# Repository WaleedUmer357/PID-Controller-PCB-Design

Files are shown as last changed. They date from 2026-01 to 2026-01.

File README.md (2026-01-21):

<h3>🔌 PCB Design Project</h3>

- <b><a href="https://github.com/WaleedUmer357/PID-Controller-">PID Controller</a></b>
  - Professional analog PID controller with TL072P operational amplifiers
  - <a href="5336317_Waleed_UMER_PID_Controller.pdf">Documentation</a> | <a href="Images/PCB_schematic.pdf">Schematic</a> | <a href="PCB.png">PCB Layout</a>

  <details>
  <summary>🎨 Click to view Project Details</summary>
  <br>
  
  <h4>🚀 Project Overview</h4>
  <p>This project showcases a professional analog PID (Proportional-Integral-Derivative) controller circuit designed and implemented using TL072P operational amplifiers. The controller was developed as part of Practical Electronics coursework at Griffith University, featuring comprehensive design, simulation, breadboard prototyping, and final PCB implementation. The system demonstrates precise control system principles with detailed analysis of P, PI, PD, and PID behaviors under various signal conditions.</p>
  
  <h4>✨ Key Features</h4>
  <ul>
    <li><b>Controller Type:</b> Analog PID Controller with adjustable parameters</li>
    <li><b>Operational Amplifiers:</b> TL072P Low-Noise JFET Op-Amps for high precision</li>
    <li><b>Frequency Range:</b> 5Hz to 20kHz operational range</li>
    <li><b>Control Stages:</b> Independent Proportional, Integral, and Derivative circuits</li>
    <li><b>Adjustability:</b> Trimpot potentiometers for real-time tuning</li>
    <li><b>Test Points:</b> Multiple test points for signal monitoring and analysis</li>
  </ul>
  
  <h4>🎯 Design Implementation</h4>
  
  <p><b>🔧 Circuit Stages Design</b></p>
  <ul>
    <li><b>Proportional Stage:</b> Gain Kp = 10 with trimpot adjustment capability</li>
    <li><b>Integral Stage:</b> Low-pass filter with cutoff frequency = 800Hz, Ki = 1</li>
    <li><b>Derivative Stage:</b> High-pass filter with Kd = 1 for rate-of-change response</li>
    <li><b>Summation Stage:</b> Standardized 1KΩ resistors with overall gain of 10</li>
    <li><b>Difference Amplifier:</b> Unit gain stage for error signal processing</li>
  </ul>
  
  <p><b>⚡ Power Requirements</b></p>
  <ul>
    <li>Dual power supply: ±12V to ±15V operation</li>
    <li>Low power consumption JFET input op-amps</li>
    <li>Stable operation across temperature variations</li>
  </ul>
  
  <p><b>📊 Signal Processing Capabilities</b></p>
  <ul>
    <li>Handles square, triangular, and sinusoidal waveforms</li>
    <li>Real-time error correction with minimal phase shift</li>
    <li>Overshoot and undershoot control through tuning</li>
    <li>Steady-state error elimination via integral action</li>
  </ul>
  
  <h4>🔬 Testing & Performance Analysis</h4>
  
  <p><b>📈 Controller Behaviors Demonstrated</b></p>
  
  <table>
    <tr>
      <td><b>Controller Type</b></td>
      <td><b>Performance Characteristics</b></td>
      <td><b>Applications</b></td>
    </tr>
    <tr>
      <td>Proportional (P)</td>
      <td>Fast response, steady-state error, oscillations</td>
      <td>Simple systems, coarse control</td>
    </tr>
    <tr>
      <td>Proportional-Integral (PI)</td>
      <td>Eliminates steady-state error, overshoot issues</td>
      <td>Temperature control, level control</td>
    </tr>
    <tr>
      <td>Proportional-Derivative (PD)</td>
      <td>Reduces overshoot, system damping, undershoot</td>
      <td>Motor control, positioning systems</td>
    </tr>
    <tr>
      <td>Full PID</td>
      <td>Optimal response, minimal error, stability</td>
      <td>Precision control systems</td>
    </tr>
  </table>
  
  <p><b>🎛️ Tuning Methodology</b></p>
  <ul>
    <li>Manual tuning via potentiometers for each stage</li>
    <li>Oscilloscope monitoring of reference vs. output signals</li>
    <li>Iterative adjustment for optimal response</li>
    <li>Frequency response analysis from 5Hz to 20kHz</li>
  </ul>
  
  <h4>🖼️ Design Gallery</h4>
  
  <p><b>📋 Complete Schematic Design</b></p>
  <p>Professional schematic showing all PID stages with component values and signal flow. Designed in Altium Designer with clear functional blocks.</p>
  PID Controller Schematic
  
  <p><b>🔌 PCB Layout - Top View</b></p>
  <p>Clean, professional PCB layout with optimized component placement. Single-sided design for easy manufacturing and assembly.</p>
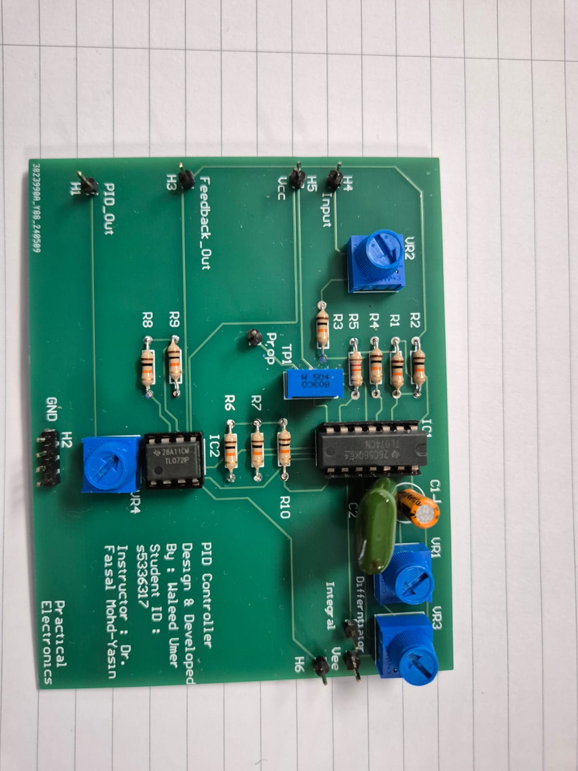
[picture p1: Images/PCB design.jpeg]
PCB Layout
  
  
  <p><b>⚡ Circuit Implementation</b></p>
  <p>Detailed view of the analog PID circuit implementation with operational amplifiers, resistors, capacitors, and tuning potentiometers.</p>
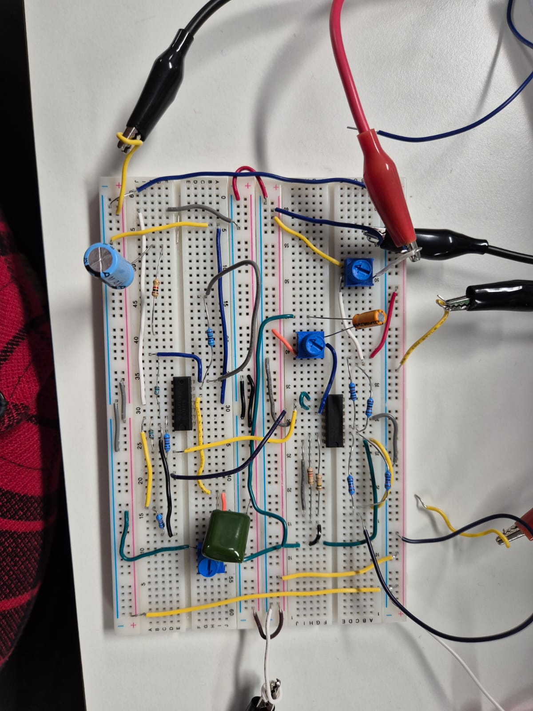
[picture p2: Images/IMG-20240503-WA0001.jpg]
Circuit Implementation
  
  
  <p><b>🧪 Breadboard Prototype</b></p>
  <p>Initial breadboard implementation used for circuit validation and parameter tuning before PCB fabrication.</p>
  <p><i>Refer to Figure 3.3 in documentation</i></p>
  
  <h4>📐 Technical Specifications</h4>
  <table>
    <tr>
      <td><b>Operational Amplifiers</b></td>
      <td>TL072P (x2), TL074 (x1)</td>
    </tr>
    <tr>
      <td><b>Power Supply</b></td>
      <td>±12V to ±15V DC</td>
    </tr>
    <tr>
      <td><b>Frequency Range</b></td>
      <td>5Hz - 20kHz</td>
    </tr>
    <tr>
      <td><b>Proportional Gain</b></td>
      <td>Kp = 10 (adjustable)</td>
    </tr>
    <tr>
      <td><b>Integral Time</b></td>
      <td>Ti = 1/(2π×800) seconds</td>
    </tr>
    <tr>
      <td><b>Derivative Time</b></td>
      <td>Td = 1/(2π×cutoff) seconds</td>
    </tr>
    <tr>
      <td><b>PCB Dimensions</b></td>
      <td>Approx. 80mm x 60mm</td>
    </tr>
    <tr>
      <td><b>PCB Layers</b></td>
      <td>Single-sided with ground plane</td>
    </tr>
    <tr>
      <td><b>Connectors</b></td>
      <td>4-pin headers for I/O and power</td>
    </tr>
  </table>
  
  <h4>📊 Performance Results</h4>
  
  <p><b>✅ Successful Outcomes</b></p>
  <ul>
    <li>Full PID functionality achieved with all control modes</li>
    <li>Effective error correction for various input waveforms</li>
    <li>Stable operation across specified frequency range</li>
    <li>Minimal overshoot with proper tuning (＜10%)</li>
    <li>Steady-state error elimination via integral action</li>
  </ul>
  
  <p><b>⚠️ Identified Limitations</b></p>
  <ul>
    <li>Frequency response limited to 20kHz maximum</li>
    <li>Low-frequency behavior resembles P-only controller below 5Hz</li>
    <li>Triangular/sinusoidal signals limited to 300Hz for full PID action</li>
    <li>Requires external load for practical applications</li>
  </ul>
  
  <h4>🔮 Applications</h4>
  <ul>
    <li><b>Temperature Control Systems:</b> HVAC, industrial process control</li>
    <li><b>Motor Speed Control:</b> DC motor speed regulation, conveyor systems</li>
    <li><b>Process Control:</b> Chemical reactors, distillation columns</li>
    <li><b>Educational Tool:</b> Control systems laboratory experiments</li>
    <li><b>Prototyping Platform:</b> PID algorithm testing and validation</li>
  </ul>
  
  <h4>📈 Comparative Analysis</h4>
  
  <p><b>PID vs. Other Controllers</b></p>
  <ul>
    <li><b>vs. P-only:</b> PID eliminates steady-state error and reduces oscillations</li>
    <li><b>vs. PI:</b> PID adds derivative action to reduce overshoot and improve stability</li>
    <li><b>vs. PD:</b> PID includes integral action to eliminate steady-state error</li>
    <li><b>Overall:</b> PID provides balanced response with fastest settling time</li>
  </ul>
  
  <h4>🔧 Design Tools & Methodology</h4>
  <ul>
    <li><b>Simulation:</b> Proteus for initial circuit validation</li>
    <li><b>Schematic Capture:</b> Altium Designer for professional schematic design</li>
    <li><b>PCB Layout:</b> Altium Designer with design rule checking</li>
    <li><b>Prototyping:</b> Breadboard for initial testing and parameter tuning</li>
    <li><b>Testing:</b> Oscilloscope for waveform analysis and performance validation</li>
  </ul>
  
  <h4>📦 Project Files</h4>
  <ul>
    <li><b>Complete Documentation:</b> <a href="5336317_Waleed_UMER_PID_Controller.pdf">PID Controller Report (PDF)</a></li>
    <li><b>Schematic:</b> <a href="PCB_schematic.pdf">Altium Schematic</a></li>
    <li><b>PCB Layout:</b> <a href="PCB.png">Manufacturing-ready Layout</a></li>
    <li><b>Circuit Diagram:</b> <a href="PCB design.jpeg">Detailed Circuit Implementation</a></li>
    <li><b>Bill of Materials:</b> Included in documentation (page 4)</li>
  </ul>
  
  <h4>💡 Future Improvements</h4>
  <ul>
    <li>Implement digital PID control using microcontroller</li>
    <li>Add auto-tuning capability for different loads</li>
    <li>Extend frequency range with higher-order filters</li>
    <li>Include load driver stage for motor/actuator control</li>
    <li>Develop graphical user interface for parameter adjustment</li>
    <li>Implement adaptive PID for varying system dynamics</li>
  </ul>
  
  <h4>📚 References</h4>
  <ol>
    <li>Åström, K. J., & Murray, R. M. (2008). Feedback Systems: An Introduction for Scientists and Engineers. Princeton University Press.</li>
    <li>Åström, K. J., & Hägglund, T. (1995). PID Controllers: Theory, Design, and Tuning. Instrument Society of America.</li>
    <li>Texas Instruments. (2020). TL07xx Low-Noise FET-Input Operational Amplifiers Datasheet.</li>
    <li>Hägglund, T., & Åström, K. J. (2004). Revisiting the Ziegler-Nichols step response method for PID control. Journal of Process Control.</li>
    <li>Ogata, K. (2010). Modern Control Engineering (5th ed.). Prentice Hall.</li>
  </ol>
  
  <p><b>Designer:</b> Waleed Umer (S5336317) | Griffith University</p>
  <p><b>Course:</b> Practical Electronics | Instructor: Dr. Faisal Mohd-Yasin</p>
  <p><b>Project Date:</b> 2024</p>
  <p><b>Tools Used:</b> Altium Designer, Proteus, Oscilloscope, Breadboard</p>
  
  </details>

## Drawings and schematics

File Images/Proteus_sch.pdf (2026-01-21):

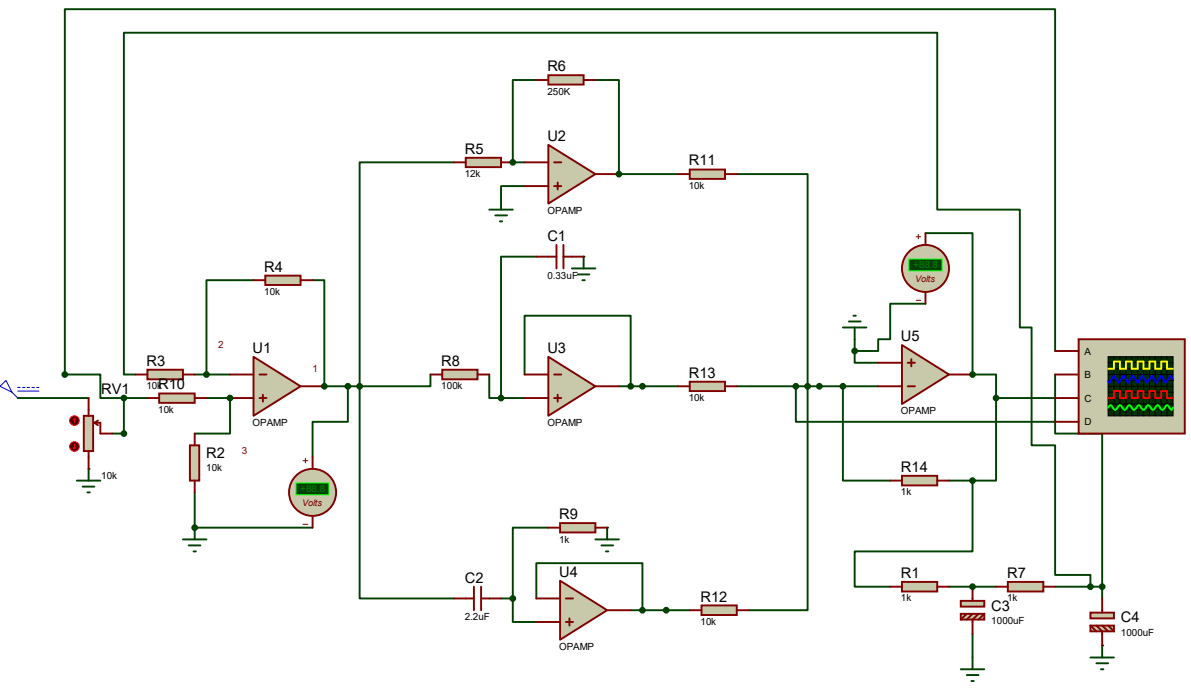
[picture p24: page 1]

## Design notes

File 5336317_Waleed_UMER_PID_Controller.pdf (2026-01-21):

PID Controller | June 6, 2024

# PID CONTROLLER

## Waleed Umer – S5336317

## PRACTICAL ELECTRONICS

### Instructor : Dr. Faisal Mohd-Yasin

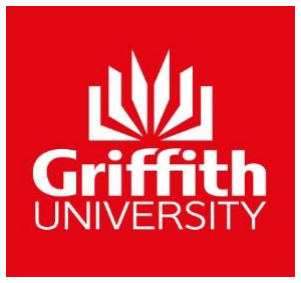
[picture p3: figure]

## CONTENTS

## 1.0 - INTRODUCTION

OBJECTIVES AND OUTCOMES

The main objective of the project is to apply the knowledge acquired in practical electronics to

the design and implementation of a PID controller. It also aims to explore and develop every

step required to build an electronic prototype. The expected results of the project will provide

a comprehensive understanding of electronic components (operational amplifiers, resistors,

capacitors, sensors, etc.) and their configurations in real-world applications.

On the topic of PID controllers, the project is detailed in its explanation. Although it does not

present any real-world applications, it explains the different modes of operation of the PID

controller—P, PI, PD, and PID—when the setpoint command is a sinusoidal, impulse,

triangular, or square wave signal.

Each mode has its advantages and disadvantages which are discussed, as are the frequencies

where these limitations exist. This analysis provides the unique advantages and disadvantages

of each mode and provides a comprehensive view of how each mode performs under different

conditions.

## 2.0 - APPLICATION

The PID controller, as we have seen, can be a useful part of the controllers we use in practical

control systems. This section will highlight three significant applications of PID controllers in

the real world:

1. Temperature control : We mentioned earlier that keeping the temperature in our houses

regulated is an essential aspect of heating, ventilation, and air-conditioning (HVAC) systems.

Not surprisingly, PID control is also commonly used in industrial applications where we need

to keep the temperature of something that can change quickly. For example, one could for

controlling the temperature in a furnace. This would be where the temperature of a furnace

must remain at a precise temperature to achieve consistent results, even with fluctuations or

disturbance in the system [4].

2. Speed control: Being able to accurately and precisely control the speed of a motor is

another application of PID control. For example, with a car engine, you want a certain amount

of gas to go in your engine to achieve a desired speed. Through PID control, one can regulate

the flow of gas into the engine to achieve a certain, desired speed. This is seen in the

automation of a conveyor belt system where you want to move a give a belt a certain speed

from the motor [5].

3. Process control: This last example can be applied in a situation where you have a chemical

process you want to control. This could be a chemical reactor where you are trying to produce

a specific amount of product Y from reactants X1 and X2. This system will run optimally with

the right amount of reactants being pumped in. A PID controller will adjust the flow rates to

make sure we have the right pressure and composition to help the distillation column run

efficiently, ensuring the results are consistent[6].

MARKET ANALYSIS

Without undergoing extensive practical tests with a load such as a DC motor, the product has

no potential commercial value for application. Nonetheless, it can be used in a range of signal

control applications within a specified range.

The below are the costs for individual components using the circuit; the minimum quantity of

PCBs that can be ordered to manufacture is five per quantity and the costs for PCB production

is $18, and the delivery charge is an additional $5.

COST OF THE PROJECT
LIST OF PARTS¹
Comment | Description | Quantity | Total Cost AUD
CAPACITOR POL | Polarized Cap | 1 | $1.92
TL074 | TL074/LF347 Quad Low Noise JFET Op-
| Amp Linear [3] | 1 | $1.58
Header 4 | Header, 4-Pin | 4 | $1.10
TL072 | TL072 Bi Low Noise JFET Op-
| Amp Linear | 1 | $1.66
RESISTOR | 1/4 W Res | 11 | $7.52
Potentiometer | Breadboard Compatible | 4 | $7.00
Manufacturing &
Delivery | Printed Circuit Board | | 18+5$

TOTAL COST OF
MATERIALS | $43.78

LABOR COST
ACTIVITY | HOURS | COST PER HOUR | TOTAL COST
Altium design | 4 | $25 | $100
Circuit wiring and testing | 12 | $25 | $300
Soldering process | 2 | $20 | $40
TOTAL COST OF LABOR | | | $440

TOTAL COST OF THE PROJECT
Developing, testing, and producing the prototype not only involves high initial costs, but also involves

relatively simple parts and functions. Our cost estimate for the materials, including PCB manufacturing

and shipping, is approximately $44 based on current online prices. For mass production, parts would be

sourced at wholesale prices significantly decreasing the costs. Our production quality and cost-

effectiveness could be enhanced by streamlining the soldering process. Overall, the total cost to develop

and produce the prototype is approximately $440.

## 3.0 -INITIAL DESIGN

BASIC THEORY

A Proportional-Integral-Derivative (PID) controller is an indispensable instrument in control

systems engineering and is ubiquitous in modern industry. It’s a system that keeps a process

within a given setpoint by minimising the error between the process variable and the setpoint.

One computes the controller output from three parts: the first one (P) relies on the current error,

a second one (I) accumulates errors over time, and a third (D) anticipates future errors by

considering the rate of change of error. Hence, the combined effect makes the system behave in

such a way that it truly knows how to deliver desired adequate tuning for precise and stable

control of a large class of dynamic systems[1],[2].

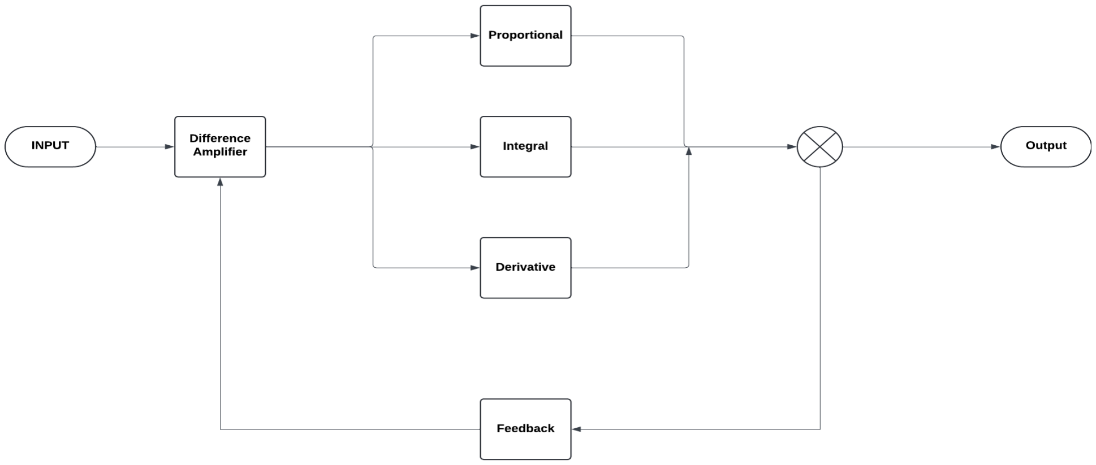
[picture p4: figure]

Figure 3.01 Basic PID Diagram

ELEMENTS OF A PID

PROPORTIONAL STAGE
Proportional is the part of a PID Controller that puts a gain on the error signal. It dictates how

much of a gain this Controller will see from the error to the setpoint. The goal is to dictate

the gain of the system, and the percent of not only the Controller but also on the overall

system. So the proportional gain (Kc) will define in turn how much but also very quickly this

system will react to this error signal. If we take a proportional gain that is very high, we can

see a very quick reaction and this system can start to ‘oscillate’.

INTEGRAL STAGE
A PID controller, on the other hand, incorporates a short-term memory that increases the

responsiveness by accumulating past errors. This accumulated value is used to change the

setpoint of the controlled output in order to bring the process variable more quickly to its

desired value. The gain of this component is determined by the chosen ratio between the

feedback capacitor and the resistor, ensuring errors of long duration will be eliminated,

eventually.

DERIVATIVE STAGE
The differentiator part of a PID controller quantifies the error’s time rate of change,

contributing a negative value to the controlled output as the growth rate of the error increases.

It reduces overshoot by slowing down system response at approach to set-point by process variable, thus, ideally preventing any overshooting. When there are big deviations in the

system, derivative component performs a significant task to ensure that it runs smoothly. It

also minimizes oscillations and helps settle down the system along with an integral portion.

ANALOGUE CIRCUITS OF PID:
The PID controller design process consisted of different stages.

Initially, the analogue circuits belonging to the proportional, integral, derivative, summation

and subtractor stages were defined. The topology used in each stage are shown below:

1. Proportional circuit:

Gain = Kp=10

We chose a moderate gain for the proportional stage to ensure that the PID output approaches

the reference value quickly, meeting our requirement for systems with moderate to high

frequencies. This not only shortens the response time but also makes it easier to observe the

PID signal intercepting the system signal, especially during demonstrations with an

oscilloscope. Initially, we set this gain, but later, we can fine-tune it to the desired value using

a Trimpot (potentiometer) simply by adjusting its knob.

2. Integral circuit:

voltage gain=Ki=1

CutOff Frequency =800Hz

To maintain circuit simplicity, the gain value of the integral stage was set to 1, and a low-pass

integral filter output was buffered with a gain of 1, deviating from the conventional integral

circuit. This adjustment streamlined circuit analysis. To offset the lack of gain in the integral,

gain was introduced to the summing stage of the PID circuit. This modification ensures proper

functionality and simplifies the overall circuit design.

3. Differentiation circuit:

Derivative gain = Kd = 1

To maintain circuit simplicity, similar to integral stage, the gain value of the derivative stage

was set to 1, and a low-pass differential filter output was buffered with a gain of 1, deviating

from the conventional differential circuit. This adjustment streamlined circuit analysis. To offset

the lack of gain in the differential stage, gain was introduced to the summing stage of the PID

circuit. This modification ensures proper functionality and simplifies the overall circuit design.

4. Summation circuit:

To simplify the design process, all resistors were standardized to the same value (1 KΩ).

Since we set gain of the integral and differential stage of the circuit , a gain of 10 is introduced

at the summation stage . This approach maintains signal integrity and facilitates

straightforward analysis and adjustment of the circuit.

5. Difference Amplifier circuit:

Similarly to the summation stage, unit gains are established for the difference amplification

stage initially to maintain the system's performance unaffected. This approach ensures

stability and consistency in the system's operation, minimizing any potential impact on its

overall performance.

ASSEMBLED PID CONTROLLER CIRCUIT:

Employing the Proteus circuit design software , entire PID controller was modelled and an

approximate response of the system was obtained. In the following image you can see the

integration of all the circuits mentioned in the previous section.

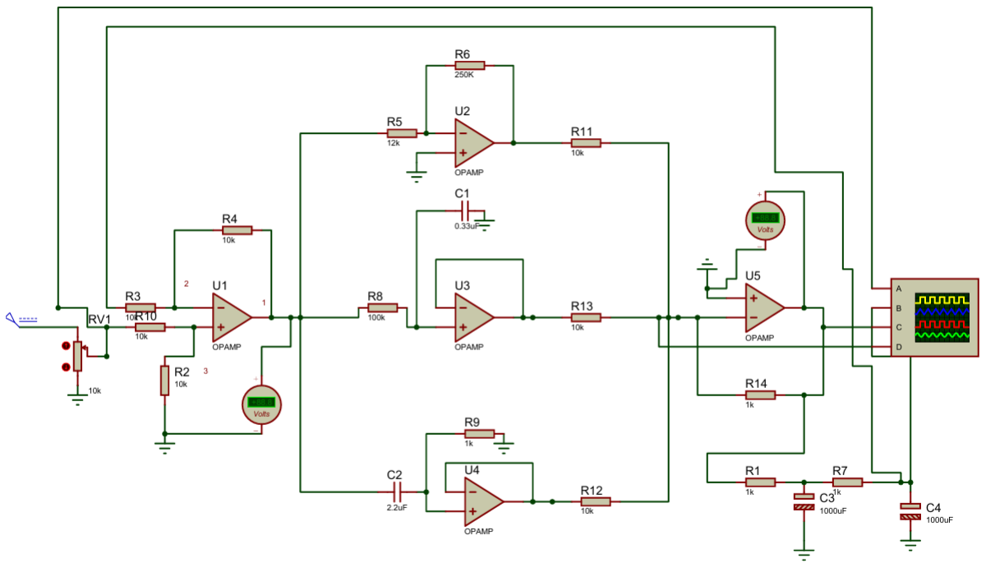
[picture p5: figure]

Figure 3.02 Proteus Implementation of PID

In this Figure 3.2 . A simulated circuit of PID controller shown on proteus

BREADBOARD CIRCUIT RESULT

The simulated system was transferred to real circuits and elements on a breadboard. The result

of this implementation is shown below Figure 3.3.

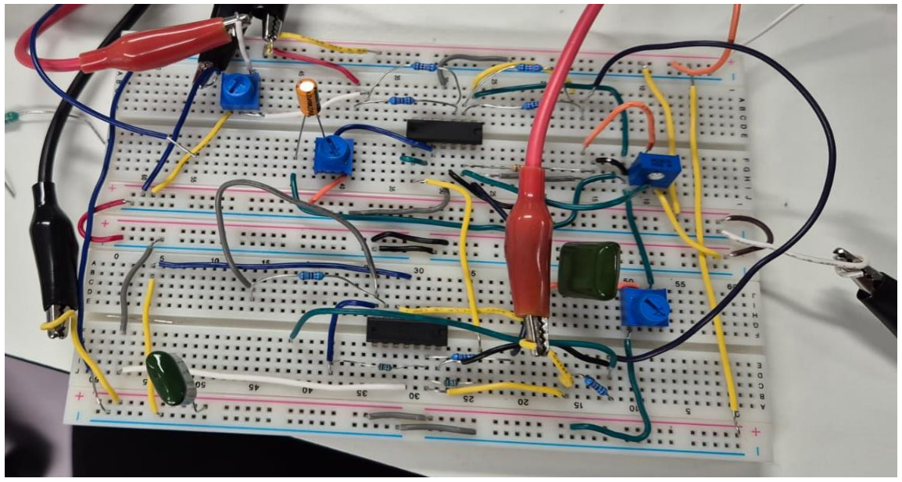
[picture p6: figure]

Figure 3.3 Breadboard Implementation of PID

This circuit played a crucial role in conducting a wide range of tests, allowing for modifications

to resistors, capacitors, op-amps, and transistors. Through these tests, we were able to define

the response characteristics of the desired PID system, subsequently obtaining the values of

fixed resistors and capacitors. These values were then applied practically on the PCB,

facilitating an efficient and effective implementation process.

ALTIUM PCB AND SCHEMATIC DESIGN

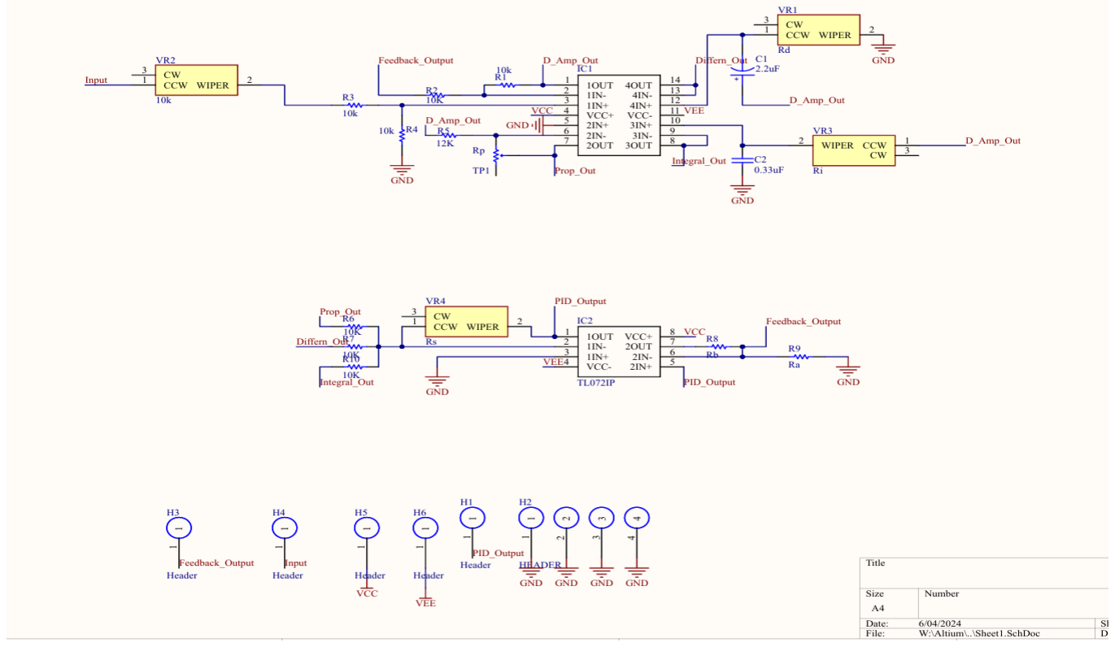
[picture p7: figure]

Figure 03.4 PCB Schematic of PID

We started our circuit design journey in Proteus, which made simulating and tweaking

component values a breeze. After settling on the initial design, we shifted gears to Altium, where

countless hours were spent refining and discussing component choices and how they fit into

our circuit.

Once we were happy with the design, we dove into PCB layout, going through three iterations

before we had a final version ready for manufacturing. We relied heavily on the component

libraries provided by the lab attendant in Altium.

We made sure to keep things simple by sticking to single-sided PCB tracks,

making manual soldering a lot easier and reducing the risk of damaging anything.

### Plus, we included a ground plane on the bottom side of the board for added

stability. Figure 3.5 shows manufacturing script of PCB design

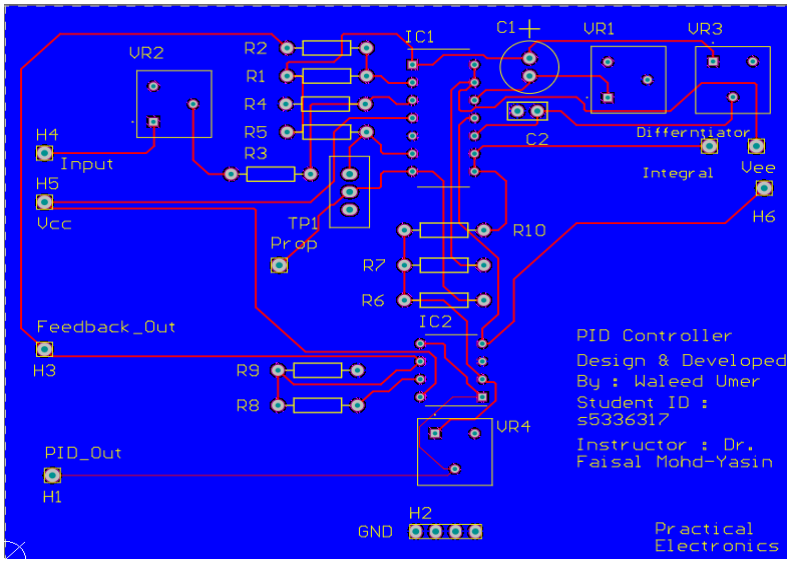
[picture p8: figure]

Figure 3.5 PCB Manufacturing Script of PID

## 4.0 – System Design Characteristics & Analysis

The system design underwent thorough testing and analysis on both breadboard and PCB

platforms, yielding valuable insights. An additional Proportional stage was introduced in the

PCB circuit as a modification. The results of various controller circuit behaviours were

categorized and explained, highlighting the benefits and drawbacks of each approach.

Throughout the analysis, it became evident that while alternative circuits showed promise in

certain scenarios, they were not preferred over a full PID controller. The drawbacks of these

circuits, such as limited control accuracy or instability, were identified and solutions were

proposed. These findings underscored the importance of a comprehensive PID controller design

for optimal performance and versatility in various control applications.

Breadboard Results
The response of this circuit measured by the oscilloscope is shown below (Figure 4.2). The

reference signal (yellow) and the PID signal (green) at different gain values for Kp , Ki and

Kd. The figure below is taken from the pre-liminary design powerpoint where I explained the

behaviour of the circuit.

Key Takeaways from Breadboard Demonstration:

- The left PID output demonstrates high stability, achieved by suppressing steady-state error

and overshoot through circuit tuning with the potentiometer.

- Conversely, the right output exhibits overshoot, indicating a need for tuning the integral value

to optimize performance.

- -The middle circuit, however, shows balanced gain values, as evidenced by the absence of

significant overshoot, or undershoot. This indicates that it effectively incorporates the

functionalities of all PID elements.

- As demonstrated in the lab, without fine-tuning the circuit for a given signal, the output can

become distorted.

- A square wave signal was chosen for demonstration due to its abrupt changes, offering a clear

illustration of the circuit's response. The same cannot be said for sinusoidal and triangular

signals, which do not provide as distinct a demonstration of the circuit's behaviour.

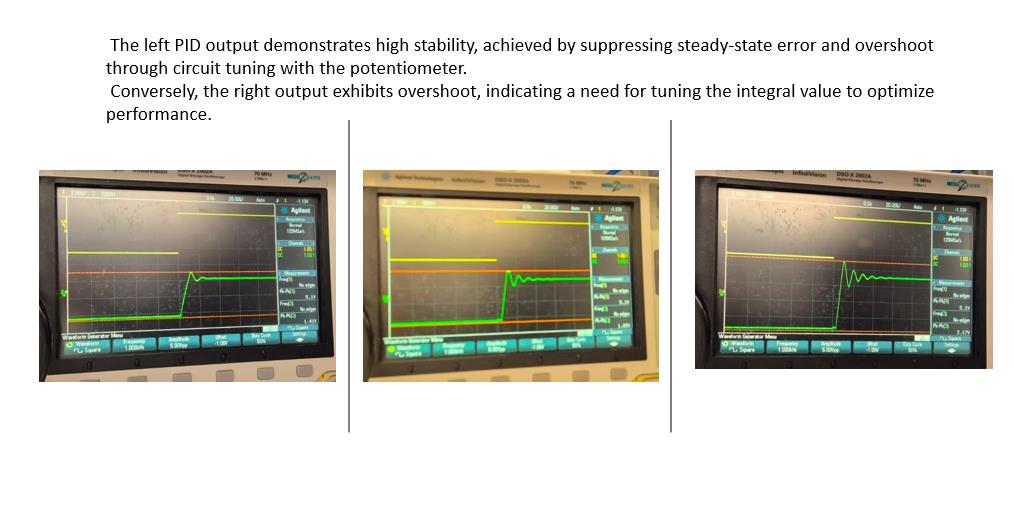
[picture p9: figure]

Figure 4.1 Breadboard results at different Tuning Values (Kp,Ki & Kd)

PRINTED CIRCUIT BOARD:

The final product is visually represented in the images below. The PCB appears clean and

compact, presenting a professional appearance. Most connections are tidy and precise,

contributing to the overall neatness of the assembly. Moreover, the PID controller operates as

anticipated, demonstrating its functionality and reliability.

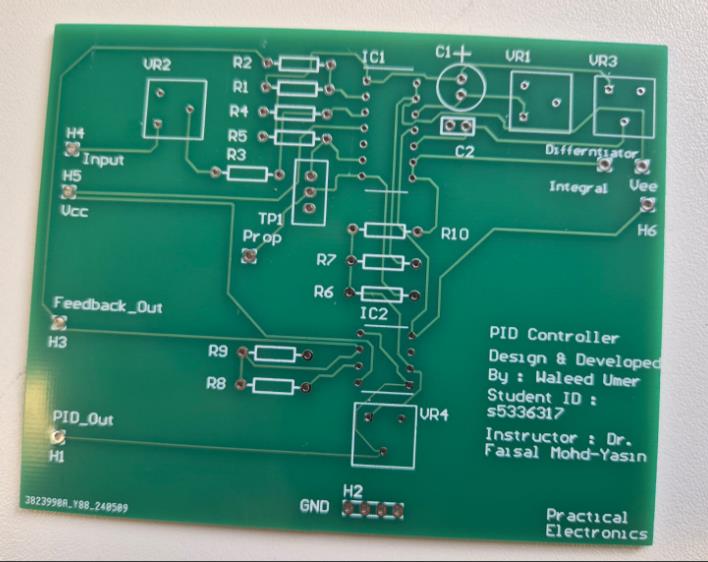
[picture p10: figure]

Figure 4.2 PCB prior to soldering components

In figure 4.3 we can observe the top view of PCB after soldering.

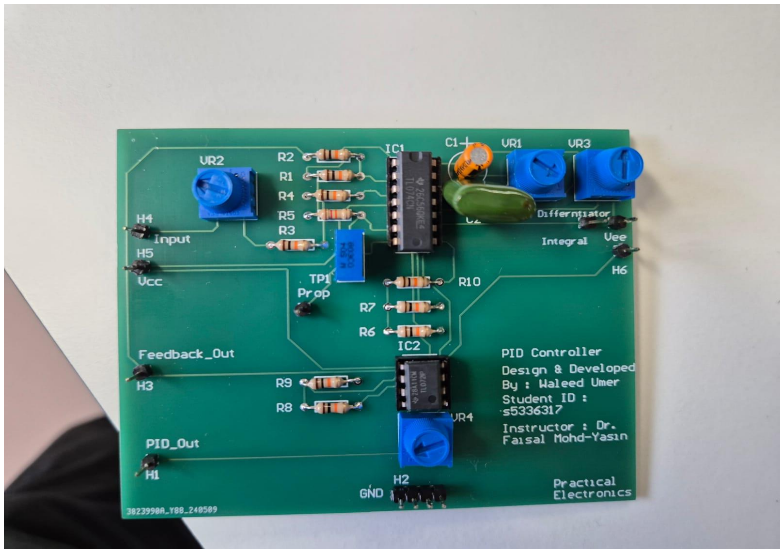
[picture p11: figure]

Figure 4.3 PCB Top View after Soldering Components

PCB RESULTS & ANALYSIS :

In this section, I conducted an in-depth analysis of PID controllers, specifically focusing

on the modification of adding a Proportional stage in front of the PID output stage to further

refine the output. Below, you will find a detailed analysis of the behaviours of P, PI, PD, and

PID circuits, along with explanations of why the full PID controller is preferred over each of

these individual control circuits.

Proportional Behaviour:

Proportional component of the circuit is known for reacting to current errors .What we

observe in the figure 4.4 below is a manifestation of P trying to correct current error (e) thus

leading to oscillations as there is no other component active we get an uncontrollable

oscillations along the length of the signal.

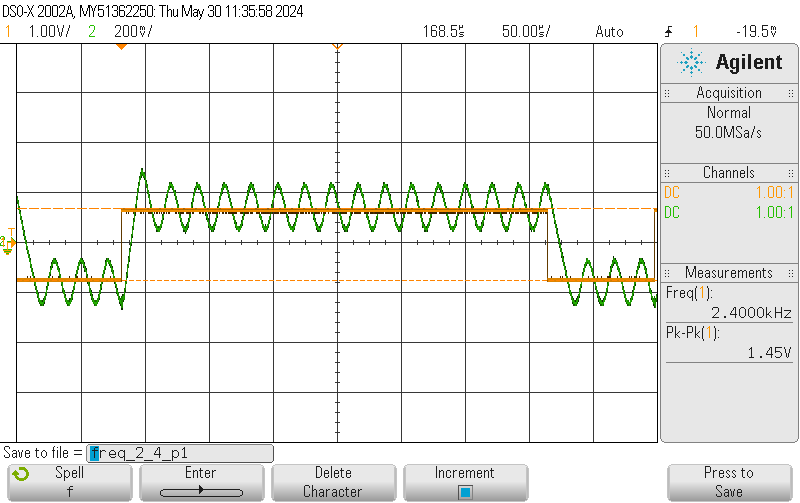
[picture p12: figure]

Figure 4.5 Proportional Behaviour

P-I Circuit Behaviour:

In this circuit, the integral component reacts to the accumulation of errors over time. Compared

to the circuit in Figure 4.4, it is evident that errors persist in this circuit, but they are gradually

reduced as the integral action works to correct past errors. However, if the integral action is too

aggressive, it can lead to high amplitude overshoots. Essentially, the proportional component

addresses current errors, while the integral component averages those errors over time, resulting

in progressively shorter oscillations. In summary, the integral component ensures steady-state

accuracy.

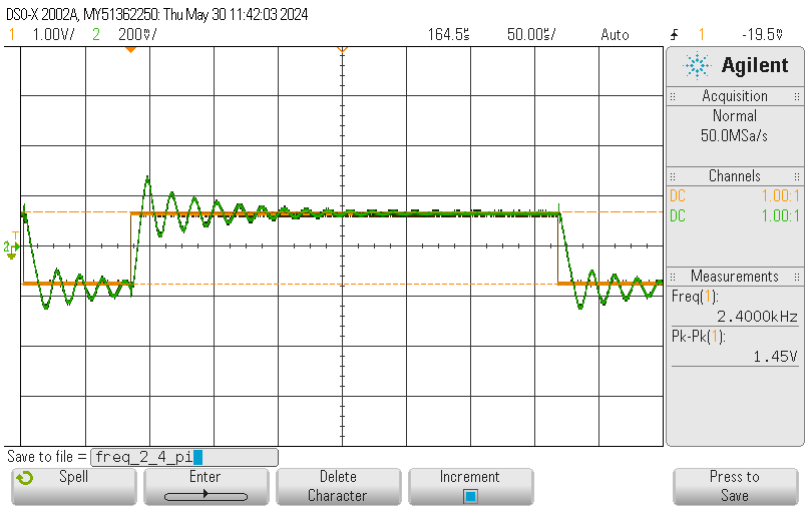
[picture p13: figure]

Figure 04.4 PI Behaviour

P-D Circuit Behaviour:

The PD circuit has behavior similar to the integral circuit as both address their errors over

time. The integral component accumulates errors over time, while the differential component

reacts to the rate of change of error, damping the system. Since the differential component

aims to counteract the effects of the proportional component, it can cause deep undershoots.

Over time, the system suppresses all oscillations as the rate of change of error approaches

zero. However, if the differential action is too aggressive, it can lead to over-damping and

instability in the system.

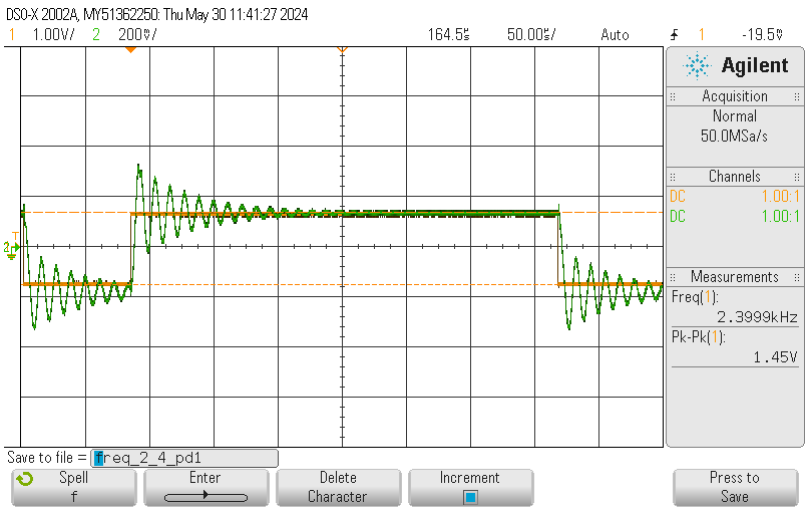
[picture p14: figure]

Figure 4.5 PD Behaviour

PID-P Circuit Behaviour (Modified PID ):

In the PCB design, I added an extra Proportional layer and removed the gain from the

summation stage to preserve the integrity of signals from each P, I, and D stage. This adjustment

was made to achieve finer control over the system and to make up for the gain not ntroduced in

the derivative and integral stages. As shown in Figure 4.7, the system error approached zero

after a single pair of undershoot and overshoot.With enhanced stability, a quicker response, fewer overshoots, and better handling of sudden changes, the PID controller proves to be more

effective than the P, PI, and PD circuits.

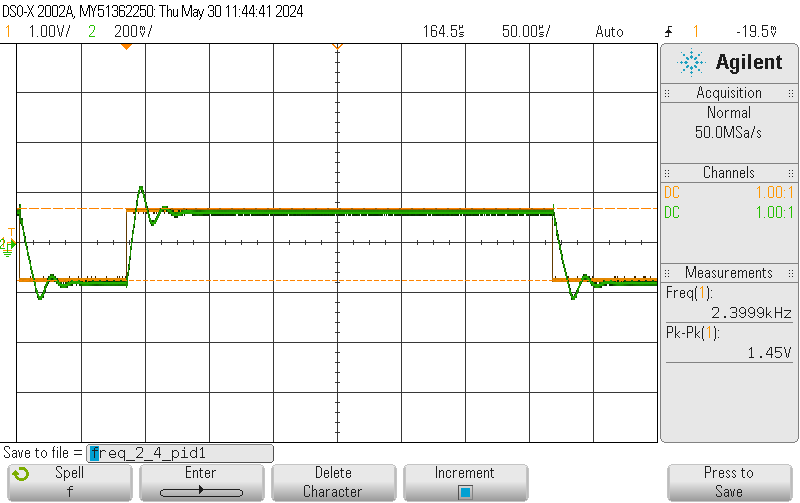
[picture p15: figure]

Figure 4.6 PID Behaviour

Comprehensive Analysis :

In Figure 4.8, I compare the behaviors of the P, PI, and PD controllers to illustrate how each

system suppresses errors. I recorded CSV data from the oscilloscope and plotted the response

of each component against the input reference signal. For clarity, I removed the reference

signal from the chart.

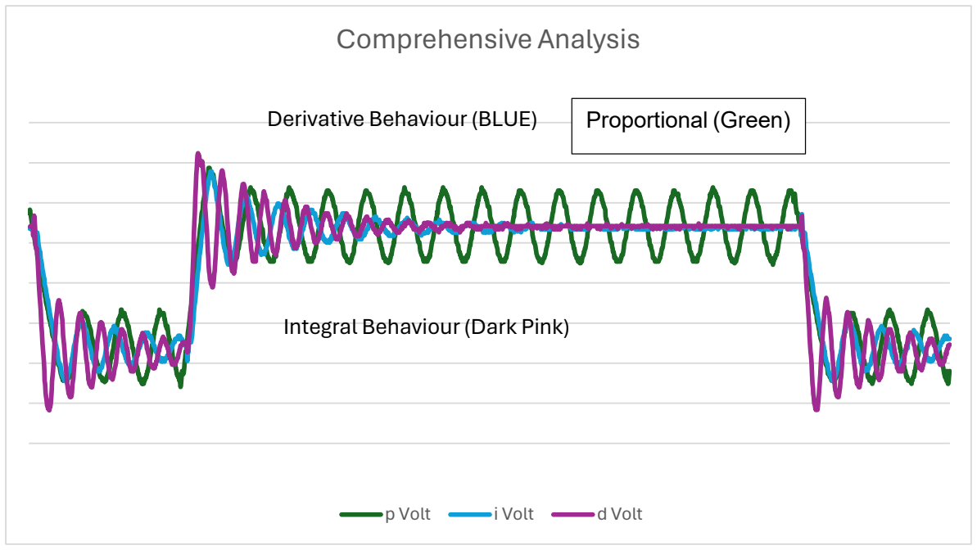
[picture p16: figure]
Comprehensive Analysis; p Volt; i Volt; d Volt; Integral Behaviour (Dark Pink); Derivative Behaviour (BLUE); Proportional (Green)

Figure 4.7 P , PI & PD Behaviour

In figure 4.9 I showed a comparison between PID and P outputs .

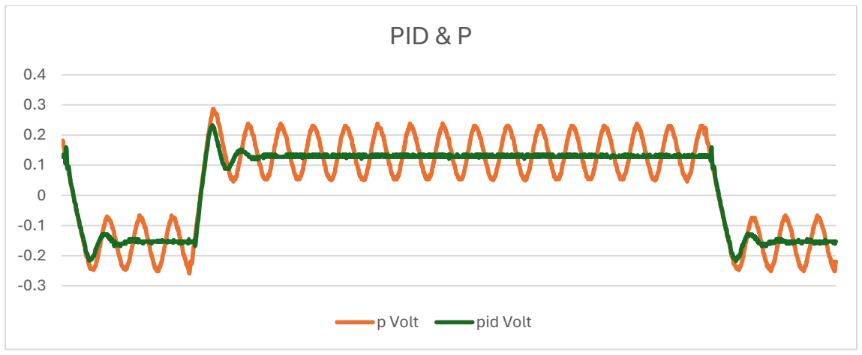
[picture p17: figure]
PID & P; p Volt; pid Volt

Figure 4.8 PID & P Comparison

In figure 4.10 I showed a comparison between PID and PD outputs. This is quite evident why

PID is preferred over PD as we get a system that has no uncontrollable overshoots. A close look

at figure 4.10 shows clear difference between amplitudes of undershoots in PID & PD.

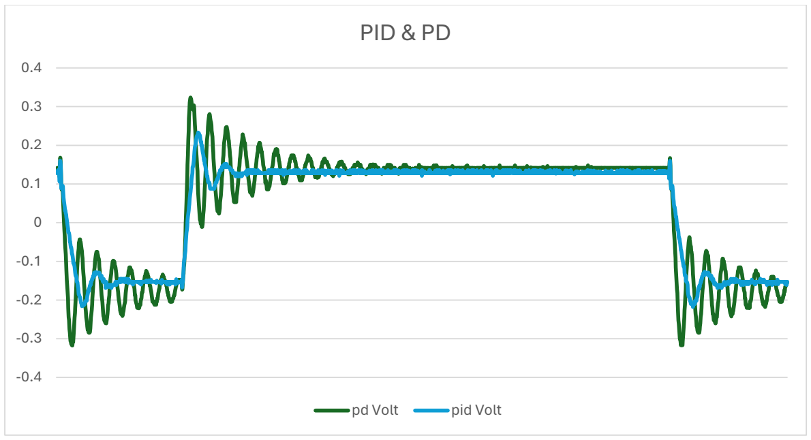
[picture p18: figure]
PID & PD; pd Volt; pid Volt

Figure 4.9 PID & PD Comparison

In Figure 4.11, I show a comparison between PID and PI behavior. The PD controller results in

overshoots, while the PI controller also exhibits overshoots. This figure clearly distinguishes

the amplitude differences between PID and PI overshoots. Increasing the integral effect can

make the system's behavior more unstable, resembling that of the PI controller.

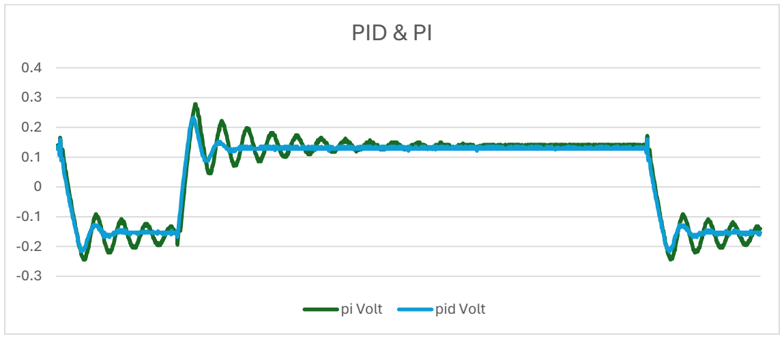
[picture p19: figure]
PID & PI; pi Volt; pid Volt

Figure 4.10 PID & PI Comparison

SOME LIMITATIONS :

KEY Takeaways

- Frequency limitations: In the final PID controller circuit, it was noted that the circuit's

frequency response ranged from as low as 5 Hz to as high as 20 kHz. At lower

frequencies, a peculiar observation was made: when the signal dropped below a

certain frequency threshold, the circuit exhibited behaviour akin to a Proportional

controller. This investigation aimed to assess the circuit's performance close to DC (0

Hz). Figure 4.12 illustrates that while the output matches the input at DC, only its

amplitude can be controlled. This phenomenon suggests that the derivative and

integral circuits do not engage in this response due to their relatively faster response

times, likely attributed to their higher capacitance.

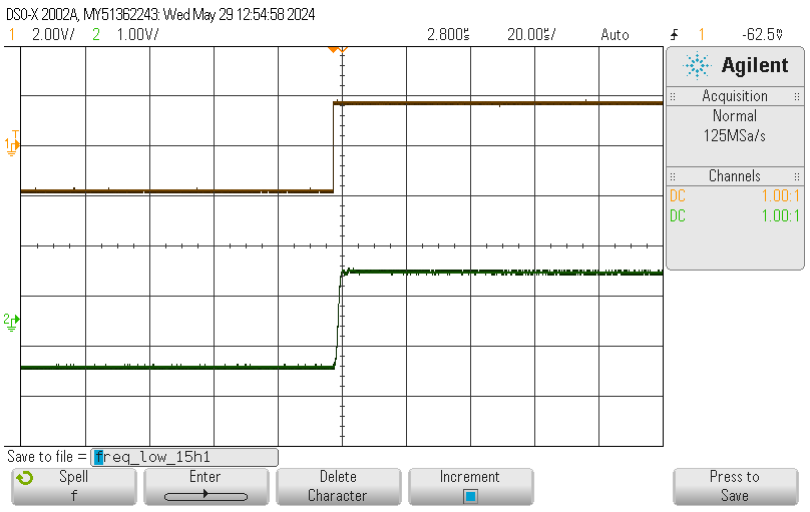
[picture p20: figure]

Figure 4.11 Low Frequency PID result

- Triangular & Sinusoidal: The frequency limitation threshold appears higher for

triangular and sinusoidal signals. These signals exhibit the behavior mentioned earlier

until approximately 300 Hz. Beyond this frequency, the effects of integral and derivative actions begin to manifest. For reference, a triangular wave is included in

Figure 4.13 to illustrate this phenomenon.

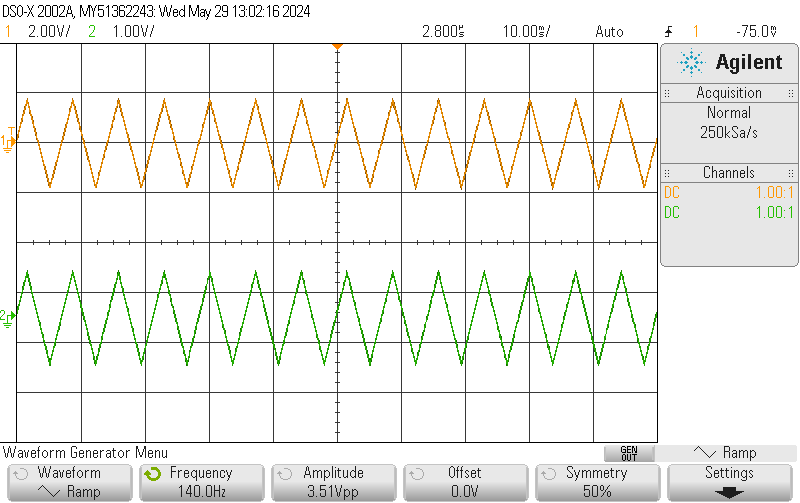
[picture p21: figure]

Figure 04.12 Triangular wave Output

- Overall, the PID results show promise for practical application. However, some

modifications may be necessary to accommodate the specific needs of the specified

application.

## 5.0 – CONCLUSION

In conclusion, the PID controller operates as intended, with modifications made to

accommodate changes resulting from the transition from conventional integral and derivative

circuits to passive circuits. These modifications effectively addressed the vacuum created by

the zero gain in the integral and derivative stages.

For future iterations of the design, improving the frequency range can be achieved by

incorporating high-order integral and derivative circuits. Additionally, the use of capacitors and

inductors can enhance the response of each stage. While this may introduce challenges in

troubleshooting, it lays a solid foundation for potential commercial applications.

However, since no load implementation was conducted for the output, commercial use is not

recommended. Nonetheless, the design provides valuable insights into the theoretical

behaviour of a PID controller and areas for improvement. It is essential to thoroughly test the

design with different loads before considering it for commercial use.

## REFERENCES

[1] K. J. Åström and R. M. Murray, Feedback Systems: An Introduction for Scientists and Engineers. Princeton, NJ: Princeton Univ. Press, 2008.
[2] K. J. Åström and T. Hägglund, PID Controllers: Theory, Design, and Tuning. Research Triangle Park, NC: Instrument Society of America, 1995.
[3] Texas Instruments. (2020, November). TL07xx Low-Noise FET-Input. Retrieved from Texas Instruments: https://www.ti.com/lit/ds/symlink/tl074.pdf
[4] T. Hägglund and K. J. Åström, "Revisiting the Ziegler-Nichols step response method for PID control," *Journal of Process Control*, vol. 14, no. 6, pp. 635-650, 2004.
[5] K. Ogata, *Modern Control Engineering*, 5th ed., Upper Saddle River, NJ, USA: Prentice Hall, 2010.
[6] W. L. Luyben, "Practical Distillation Control," *AIChE Journal*, vol. 48, no. 5, pp. 889-894, 2002.

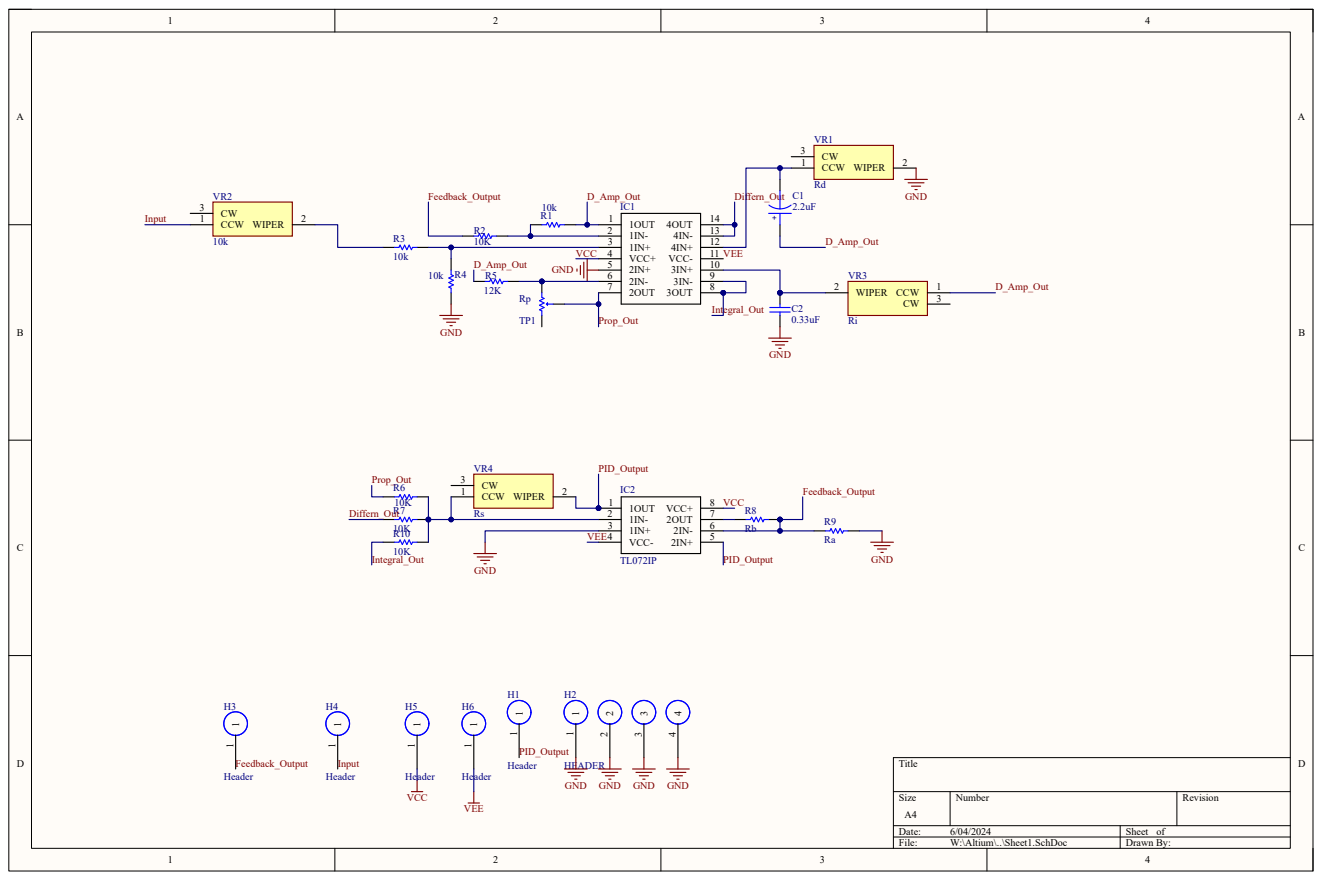
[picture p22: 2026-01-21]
Images/PCB_schematic.png

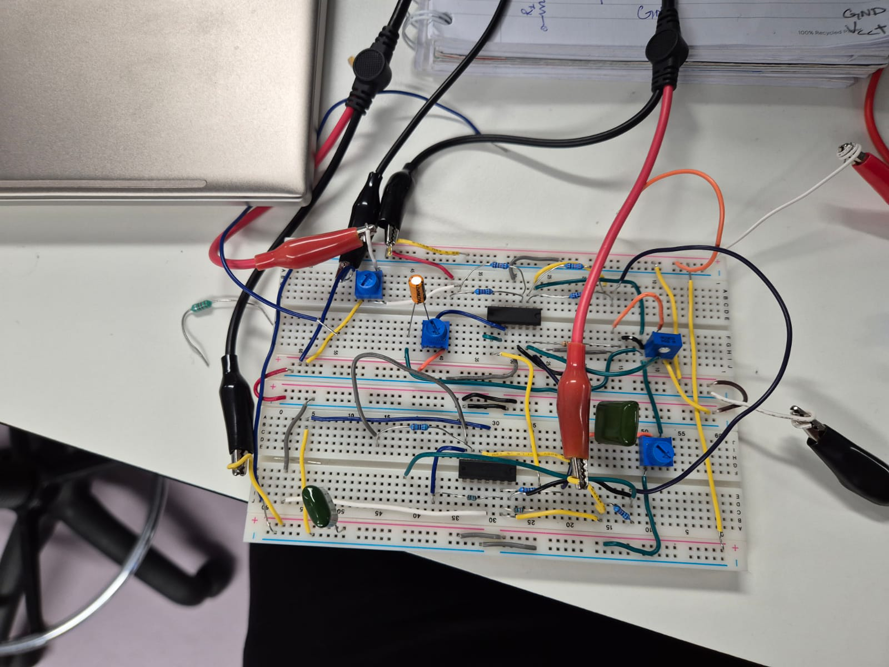
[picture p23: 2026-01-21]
Images/IMG-20240503-WA0002.jpg
